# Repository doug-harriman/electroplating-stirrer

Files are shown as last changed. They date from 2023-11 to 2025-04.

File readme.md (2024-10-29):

View this project on [CADLAB.io](https://cadlab.io/project/27601).

# Firmware

## Compiler

`sudo apt install make gcc-avr avr-libc avrdude`

## Programmer

* [Amazon](https://www.amazon.com/gp/product/B09X1W2TPG/)
* [SparkFun Docs](https://www.sparkfun.com/products/11801)

### WSL USB

**Note** [Simplexity documentation](https://simplexity.atlassian.net/wiki/spaces/FWSW/pages/2658566527/Docker#Host-Access) on forwarding USB to a Docker container in WSL.

Overview of [WSL USB access](https://learn.microsoft.com/en-us/windows/wsl/connect-usb).

1. Install the WSL drivers for your kernel.
    1. Open a WSL terminal and run `usbipd list`.  This will display packages that need to be installed for your WSL kernel.
    1. Install those packages.

1. Install the [programmer Windows driver](https://github.com/adafruit/Adafruit_Windows_Drivers/releases) & plug in the programmer.
   * Windows device manager should now show `libusb-win32 devices -> USBtiny`

1. Make the USB device available to WSL
    1. Open a WSL shell.
    1. List available USB devices: `usbipd.exe list`.  Find the `USBtiny` device and note the bus ID.
        * Note: This is calling a Windows executable from WSL.
    1. Attach the USB device to WSL: `usbipd.exe wsl attach --busid <bus ID>`.  The device should now be available in WSL.
        * When you're done with the device, detach with the command above, substituting `detach` for `attach`.
    1. Verify the device is available in an WSL terminal: `lsusb`.  The device should be listed.

1. Create a `udev` rules file to make the device accessible to `avrdude`.
    1. After attaching the device to WSL per above, run `lsusb` to get the `idVendor` and `idProduct` values needed next.  The output should look something like this:
        ```
        Bus 001 Device 002: ID 1781:0c9f Multiple Vendors USBtiny
        ```
        In this example (default for the usbtiny programmer), the `idVendor` is `1781` and the `idProduct` is `0c9f`.

    1. Create a file `/etc/udev/rules.d/99-usb.rules` with the following contents:
        ```
        SUBSYSTEM=="usb", ATTR{idVendor}=="1781", ATTR{idProduct}=="0c9f", MODE="0660", GROUP="plugdev"
        ```
        * The `idVendor` and `idProduct` values are from the output of `usbipd list` above.
    1. Add your user to the group.  This will require logging out and back in.
        ```
        sudo usermod -a -G plugdev $USER
        ```
    1. Reload the `udev` rules: `sudo udevadm control --reload-rules && sudo udevadm trigger`

    NOTE: If you're unable to access, try with `sudo` permissions.

https://devblogs.microsoft.com/commandline/connecting-usb-devices-to-wsl/

https://www.krekr.nl/content/using-usbtinyisp-with-ubuntu/
https://www.tonymitchell.ca/posts/programming-avr-in-wsl-tips-and-tricks/

## Simulator

[SimAVR](https://github.com/buserror/simavr)

`sudo apt install simavr`

also installs `gdb-avr` as a dependency.

To run a simulation, you need a special build that brings in simulator symbols.
See `main-sim.c`

`make sim`

If you run the simulator with the `-g` flag, it will open up a gdb server port.
You can then attach a GDB session to that port.

## Debugger

* VSCode launch target defined in `.vscode/launch.json`
* `make sim-debug` to build the debug target and lanch the gdb-avr server process.
    * Needs to be redone every code change.
    * Make sure to kill the debugger if you relaunch.
* Select the VSCode debug and run with the AVR Debug configuration.

# Electronics

## AtTiny85

[Amazon](https://www.amazon.com/gp/product/B0CHQ97KQZ/)
* \$13.29 for 5 pieces = $2.66/piece, though had free deliverey.
* Digikey has for \$1.66/piece in quantity 1, $1.52 in quantity 25.

## Servo Motor

[Amazon](https://www.amazon.com/gp/product/B092VN3MTX/)

## Poteniometer

[Amazon](https://www.amazon.com/gp/product/B09897HR3C/)

  You may need to install the following packages for this specific kernel:
    linux-tools-5.15.90.1-microsoft-standard-WSL2
    linux-cloud-tools-5.15.90.1-microsoft-standard-WSL2

  You may also want to install one of the following packages to keep up to date:
    linux-tools-standard-WSL2
    linux-cloud-tools-standard-WSL2

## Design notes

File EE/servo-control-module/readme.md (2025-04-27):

# Workflow

> **Note**: For all operations, keep grbl software running and maintain XY home position.

> **Note**: [CADLAB.io](https://cadlab.io/project/27601/main/files) view of github repo.  Login with google account.

## PCB Prep

1. Clean the PCB with metal polisher to remove oxidation.  I use [Brasso](https://www.amazon.com/gp/product/B0000DCZ2X/).  PCB should be shiny and clean.
1. Spray paint the PCB.  Ideally would use solder mask, but the epoxy material is hard to fully ablate.  Paint ablates nicely, though it is prone to scratching.

## Design Prep
1. Panelize PCB using KiKit.  Use to provide frame and tabs with mousebites.  The `kikit.sh` script performs the process.
1. Load the panelized PCB into KiCAD.
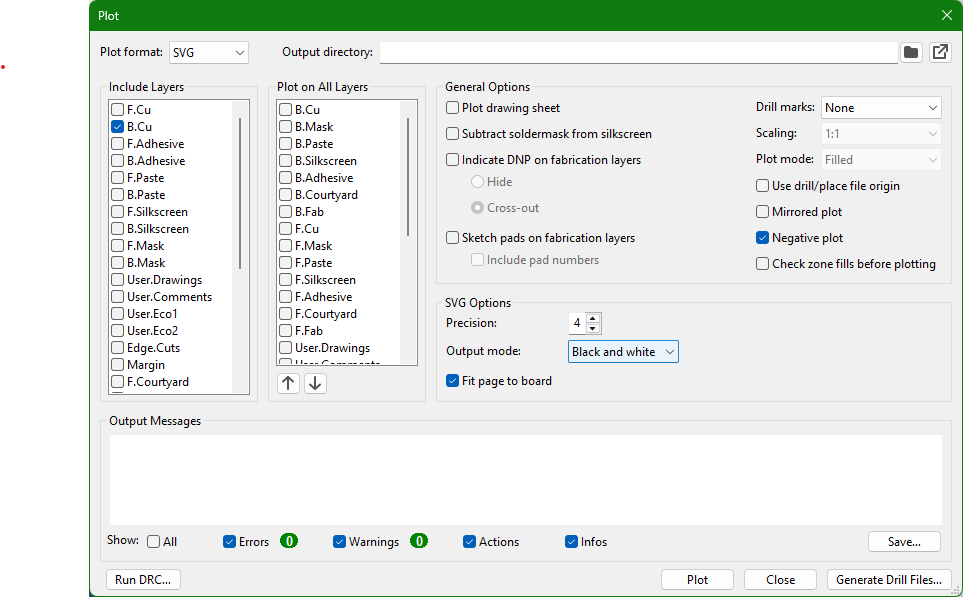
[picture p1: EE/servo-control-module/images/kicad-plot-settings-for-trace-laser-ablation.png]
PCB plot settings
1. Export a PCB image for laser ablation of the paint to expose the trace isolation areas.  Use the KiCAD "plot" function.  The image below shows the settings, assuming we're exposing the back side copper. 

## PCB Fabrication

1. Tape down PCB on mill.  Rough cut the PCB to size if that makes sense.
1. Expect to route/drill through the PCB into the supporting material, so use a sacrificial material.
1. Drill all holes, including tooling holes.
    * It is recommended
1. Route out panel from larger PCB.  Limit size of PCB we're working with to maintain chem etch solution.
1. Laser ablate spray paint in the PCB trace inverse to expose the copper for etching.
1. Chem etch the PCB to isolate the traces.
1. Laser ablate the spray paint on the solder pads.

### PCB Milling Operations

* Milling operations are generated using `pcb2gcode`.  This is a command line program that reads information from configuration files.
* `pcb2gcode` is called multiple times with different configuration files to generate the different G-code jobs (with different tools) required to machine out the PCB.

## KiCAD

KiCAD Gerber export: disable the "Use extended X2 format" option.

## PCB2GCODE

> Alternate software: https://sourceforge.net/p/pygerber2gcode/code/ci/master/tree/

* This tool worked great for generating G-code.
    * Much easier to use than FlatCAM.
    * Man page in file `pcb2gcode.pdf`.
* Example config file: `millproject`
* Generate code by running `pcb2gcode` in the same directory with `millproject`.
* Use a short list of drill sizes, or it will use exact drill size for each part.  That can lead to a lot of tooling changes.
* You can get some parameter by editing and running `pcb_calcs.py`.
    * The copper layer is very thin.  Got nice isolation with a margin of 0.5, could probably go lower.
    * This calcs the Z depth for drilling and edge cuts to cut into the tape.  It can be a bit tricky if you don't apply the height map.  Not clear if you can apply the height map to multiple files.
* Bridges shouldn't be necessary if you don't cut too fast on the edge cuts.
* Example call: https://gist.github.com/bullestock/87ed51aaadaae8b8d2f085756652eb04

## Soldermask & Silkscreen

Intended process is to apply two layers of soldermask/ink to the PCB, then use my UV laser to ablate the areas that I don't want filled in.  Overall technique from: https://www.youtube.com/watch?v=NuJlgw7E7vg.

Soldermask & silkscreen cating goes down nicely with silkscreen netting & squeegee.

* Use a squeegee to spread the ink.  I used Silicone squeegee from [Amazon](https://www.amazon.com/gp/product/B091KQFQVG/).
* Cure with UV light.  I use a resin printer cure station for 3 min with board leaning against lamp.

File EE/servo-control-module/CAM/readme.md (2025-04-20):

## Workflow

Note: For all operations, keep grbl software running and maintain XY home position.

### PCB Prep

1. Clean the PCB with metal polisher to remove oxidation.  I use [Brasso](https://www.amazon.com/gp/product/B0000DCZ2X/).  PCB should be shiny and clean.
1. Spray paint the PCB.  Ideally would use solder mask, but the epoxy material is hard to fully ablate.  Paint ablates nicely, though it is prone to scratching.

### Design Prep
1. Panelize PCB using KiKit.  Use to provide frame and tabs with mousebites.

### PCB Fabrication

1. Tape down PCB on mill.  Rough cut the PCB to size if that makes sense.
1. Expect to route/drill through the PCB into the supporting material, so use a sacrificial material.
1. Drill all holes, including tooling holes.
1. Route out panel from larger PCB.  Limit size of PCB we're working with to maintain chem etch solution.
1. Laser ablate spray paint in the PCB trace inverse to expose the copper for etching.
1. Chem etch the PCB to isolate the traces.
1. Laser ablate the spray paint on the solder pads.

# TODO

- [] Infill should not retrace.  Do bi-di laser cutting.
- [] G2 format is wrong.  Getting rejected by LaserGRBL as an invalid code.
    - Proper G2: From wherever you are, you will start. Specify the XY end point withing the G2 command.  I&J represent the center delta from the start point to the end of the arc.

Another project: https://sourceforge.net/p/pygerber2gcode/code/ci/master/tree/

## KiCAD

KiCAD Gerber export: disable the "Use extended X2 format" option.

## PCB2GCODE

* This tool worked great for generating G-code.
    * Much easier to use than FlatCAM.
    * Man page in file `pcb2gcode.pdf`.
* Example config file: `millproject`
* Generate code by running `pcb2gcode` in the same directory with `millproject`.
* Use a short list of drill sizes, or it will use exact drill size for each part.  That can lead to a lot of tooling changes.
* You can get some parameter by editing and running `pcb_calcs.py`.
    * The copper layer is very thin.  Got nice isolation with a margin of 0.5, could probably go lower.
    * This calcs the Z depth for drilling and edge cuts to cut into the tape.  It can be a bit tricky if you don't apply the height map.  Not clear if you can apply the height map to multiple files.
* Bridges shouldn't be necessary if you don't cut too fast on the edge cuts.
* Example call: https://gist.github.com/bullestock/87ed51aaadaae8b8d2f085756652eb04

## Soldermask & Silkscreen

Intended process is to apply two layers of soldermask/ink to the PCB, then use my UV laser to ablate the areas that I don't want filled in.  Overall technique from: https://www.youtube.com/watch?v=NuJlgw7E7vg.

Soldermask & silkscreen cating goes down nicely with silkscreen netting & squeegee.

* Use a squeegee to spread the ink.  I used Silicone squeegee from [Amazon](https://www.amazon.com/gp/product/B091KQFQVG/).
* Cure with UV light.  I use a resin printer cure station for 3 min with board leaning against lamp.

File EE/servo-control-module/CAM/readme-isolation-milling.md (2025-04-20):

> NOTE: This file is deprecated, captures info from when trying to do isolation routing of traces instead of chem etching.

# TODO

- [] Infill should not retrace.  Do bi-di laser cutting.
- [] G2 format is wrong.  Getting rejected by LaserGRBL as an invalid code.
    - Proper G2: From wherever you are, you will start. Specify the XY end point withing the G2 command.  I&J represent the center delta from the start point to the end of the arc.

Another project: https://sourceforge.net/p/pygerber2gcode/code/ci/master/tree/

# PCB Milling

[Good overall resource](https://hobbycnc.com/pc_board_isolation_routing/pc-board-isolation-routing-kicad/)

## KiCAD

KiCAD Gerber export: disable the "Use extended X2 format" option.

## PCB2GCODE

* This tool worked great for generating G-code.
    * Much easier to use than FlatCAM.
    * Man page in file `pcb2gcode.pdf`.
* Example config file: `millproject`
* Generate code by running `pcb2gcode` in the same directory with `millproject`.
* Use a short list of drill sizes, or it will use exact drill size for each part.  That can lead to a lot of tooling changes.
* You can get some parameter by editing and running `pcb_calcs.py`.
    * The copper layer is very thin.  Got nice isolation with a margin of 0.5, could probably go lower.
    * This calcs the Z depth for drilling and edge cuts to cut into the tape.  It can be a bit tricky if you don't apply the height map.  Not clear if you can apply the height map to multiple files.
* Bridges shouldn't be necessary if you don't cut too fast on the edge cuts.
* Example call: https://gist.github.com/bullestock/87ed51aaadaae8b8d2f085756652eb04

## Mounting PCB

It is *very* important to get the board as flat as possible.  The painters tape glued together does seem to work well if:
* Mounted to the aluminum plate, not the MDF spoilboard.
* Clean the aluminum with isopropal alcolhol ahead of time so tape adheres well.
* While glue is drying, put a large weight on the PCB.  A 5 lb sledge hammer worked well.

## Tooling

The 60 degree triangular V-cut bits worked very well.  Robust bit, and isolated nicely.
* [Inventree](http://192.168.0.120:8800/part/48/)
* [Amazon](https://www.amazon.com/gp/product/B08881PKBN?th=1)

## Autoleveling

* Use CNCjs autolevel module: https://github.com/kreso-t/cncjs-kt-ext
    * This is loaded on the Shop Server, in the CNCjs VM.
    * It's in directory `~/tmp/cncjs-kt-ext/`
    * It must be restarted every time the USB connection is made.
        * `>> node . --port /dev/ttyUSB0`
    * Create a macro or run from the command line:
        * `(#autolevel D7.5 H1.0 F20)`
        * `F` - Z-probe speed, don't go lower than 20 (mm/sec).
        * `D` - Grid spacing.  Defaults to 10 (mm).

## Soldermask & Silkscreen

Intended process is to apply two layers of soldermask/ink to the PCB, then use my UV laser to ablate the areas that I don't want filled in.  Overall technique from: https://www.youtube.com/watch?v=NuJlgw7E7vg.

Soldermask goes down nicely with:
* Cover with plastic film (overhead film works well). Need rigitity.  Plastic wrap is too soft.
* Use a squeegee to spread the ink.  I used Silicone squeegee from [Amazon](https://www.amazon.com/gp/product/B091KQFQVG/).
* Cure with UV light.  I use a resin printer cure station for 3 min with board leaning against lamp.

Essentially:
1. Lay down & cure the base soldermask (color of choice)
2. Ablate soldermask in areas where you want silkscreen.
3. Apply white ink/soldermask & cure
4. Ablate solder pads: 80% power, 200 mm/sec

### Software Tooling

While FlatCAM is a very impressive piece of Python GUI software, it's cumbersome to have to do a lot of manual stuff.  Per above, `PCB2GCODE` does a great job with the isolation routing, edge routing and drilling G-code file generation.  Once you've properly parameterized your system, it's a two second opeation to go from Gerber to G-Code.  Looking to add in the next steps in that tooling for laser ablation paths.

We need to go from Gerber to G-Code. [Gerbonara](https://gerbolyze.gitlab.io/gerbonara/#) can read Gerber files and provide graphics primitives which can be converted to G-Code by a custom Python module `gbr2grbl.py`.  This is able to draw and fill rectangles and circles, which meets the most basic of soldermask needs.

With a "dumb" implementaiton, just generating G-code geometry,
* With 0.1mm infill step size, CAMotics estimates:
    * Job time: 1m 21s
    * Total distance: 1378.1 mm.
* No infill
    * Job time: 15s
    * Total distance: 239.2 mm.

With 2D position scheduling optimization
* With 0.1mm infill step size, CAMotics estimates:
    * Job time: 1m 18s (3.7% savings)
    * Total distance: 778.0mm (43.5% savings)
* With no infill, CAMotics estimates:
    * Job time: 14.9s (0.7% savings)
    * Total distance: 222.1mm (7.1% savings)

With Traveling Salesman optimization (greedy tsp):
* With no infill, CAMotics estimates:
    * Job time: 14.93s (0.7% savings)
    * Total distance: 227.4mm (7.1% savings)

To do:

- Looks like need to flip bottom side image.
- Verify home position is correct.
- Add in laser G-code parameters as TOML config file.
- Add generation of other g-code files handled by `pcb2gcode` (drill, edge route, isolation route).
- Parameterize `pcb2gcode` to use the same TOML config file.
- Use `.gbrjob` data for `pcb2gcode` config.  Stackup has PCB and Cu thicknesses.
- Make sure I have the stackup config correct in the KiCAD PCB file.

## Overall Process

Note: For all operations, keep grbl software running and maintain XY home position.

1. Mount bare PCB to a flat but sacrificial material which is clamped to the mill bed.  PCB mounting via glued tape attached to both surfaces.  Doublesided tape will work well also.
2. If the PCB is double sided, drill corner holes that can be fitted with dowell pins for locating.
3. Autolevel board
4. Isolation route PCB back side.  Start with back side to minimize flips (assuming silksceen is front side only).
5. If double sided: clean PCB apply and cure back side soldermask, flip board, repeat steps 3 & 4 for front side.
6. Clean PCB, apply & cure soldermask.
8. Mount laser.
9. Ablate silkscreen image.
10. Apply & cure silkscreen ink
11. Ablate soldermask for solder pads
12. Remount spindle
13. Drill
14. Edge route
15. Tin exposed pads.

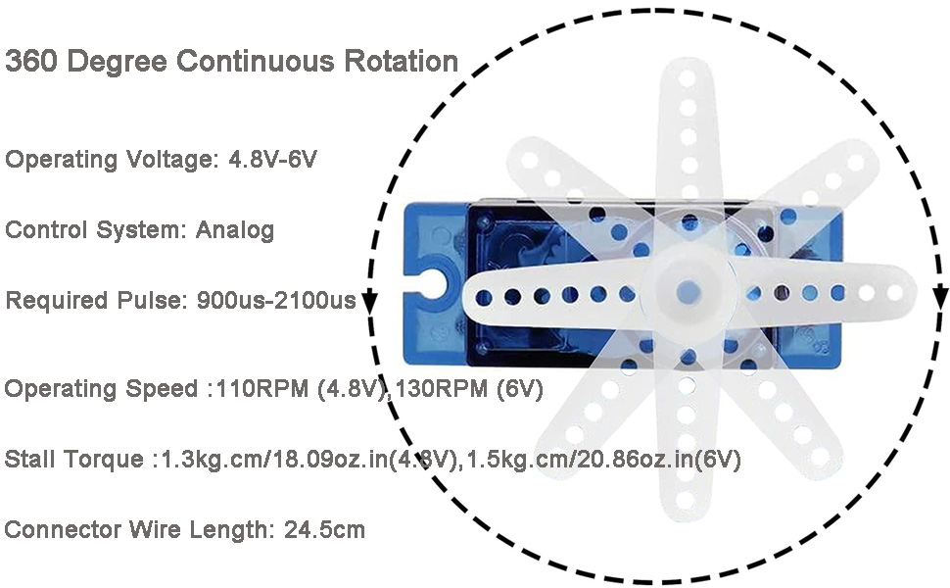
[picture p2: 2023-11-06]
Media/servo-specs.jpg

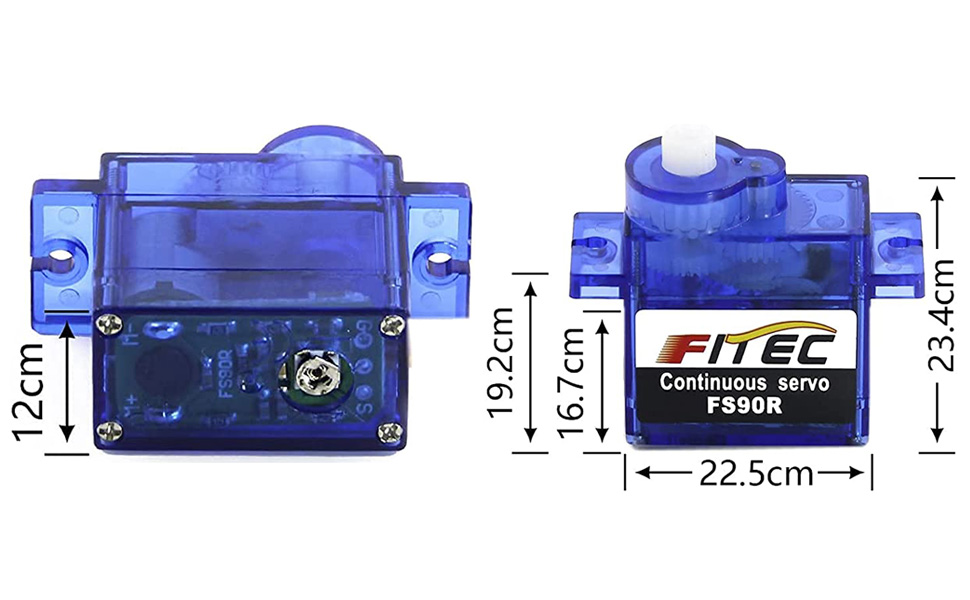
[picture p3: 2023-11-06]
Media/servo-mechanical.jpg

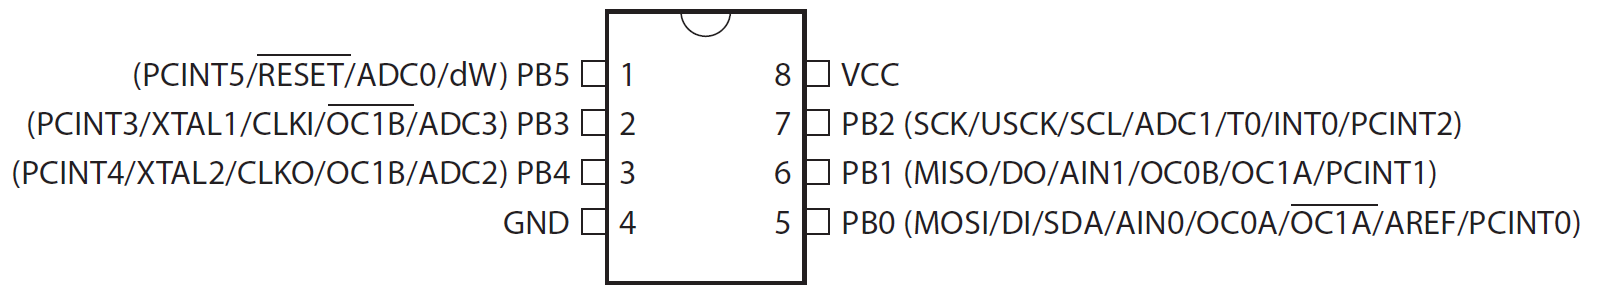
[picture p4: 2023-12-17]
EE/servo-control-module/ATtiny85-Pinout.png

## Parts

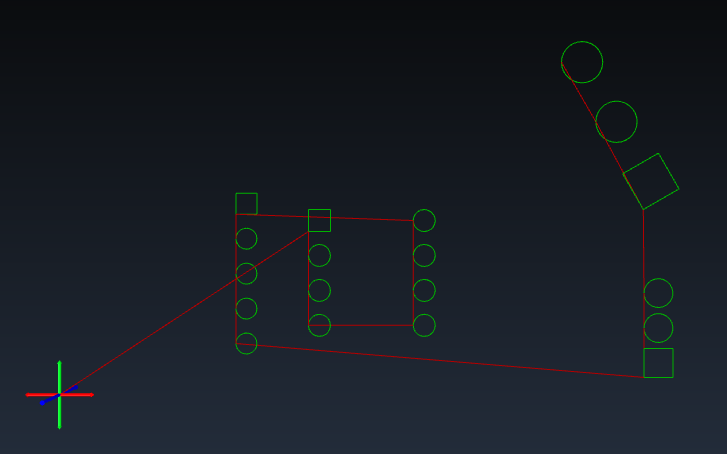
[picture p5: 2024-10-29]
EE/servo-control-module/CAM/gcode-gen-per-gerber-geometry-order.PNG

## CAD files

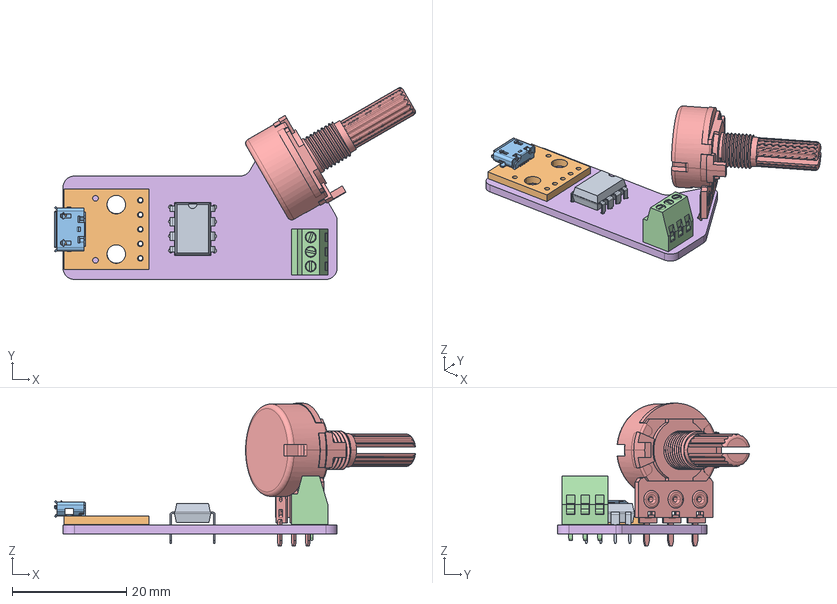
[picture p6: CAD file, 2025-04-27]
ME/PCA-with-Components.FCStd
63.2 x 33.6 x 25.0 mm
DIP-8_W7.62mm
PCA-USB-micro-breakout001
PCA-USB-micro-breakout002
kit-3pos-screw-down-terminal001
Potentiometer002
servo-control-module_PCB

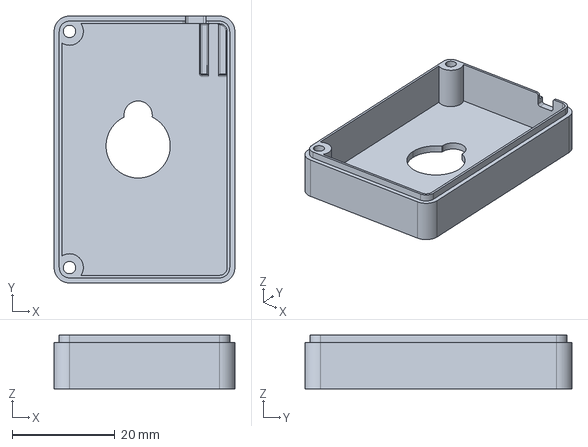
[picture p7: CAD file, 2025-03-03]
ME/Chassis-Lower.FCStd
35.2 x 52.0 x 10.5 mm

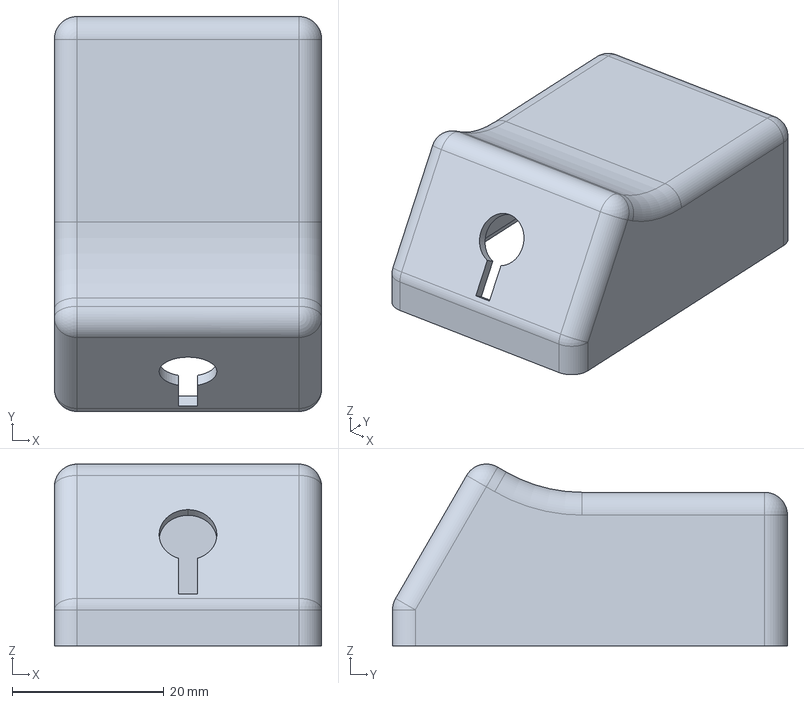
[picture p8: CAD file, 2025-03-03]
ME/Chassis-Upper.FCStd
35.2 x 52.0 x 23.9 mm

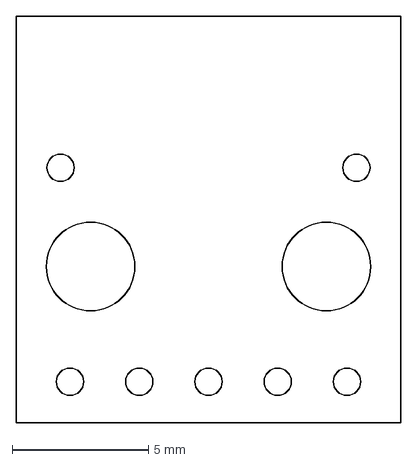
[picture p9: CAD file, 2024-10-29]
ME/PCB-USB-micro-breakout.DXF
14.1 x 14.9 mm

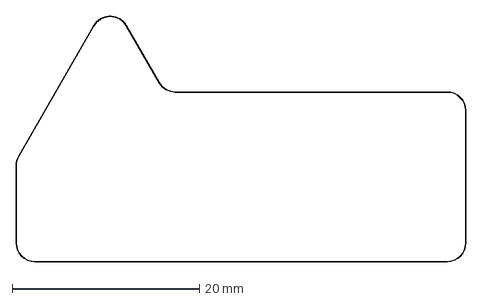
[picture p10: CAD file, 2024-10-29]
ME/pcb-speed-control.DXF
48.0 x 26.2 mm

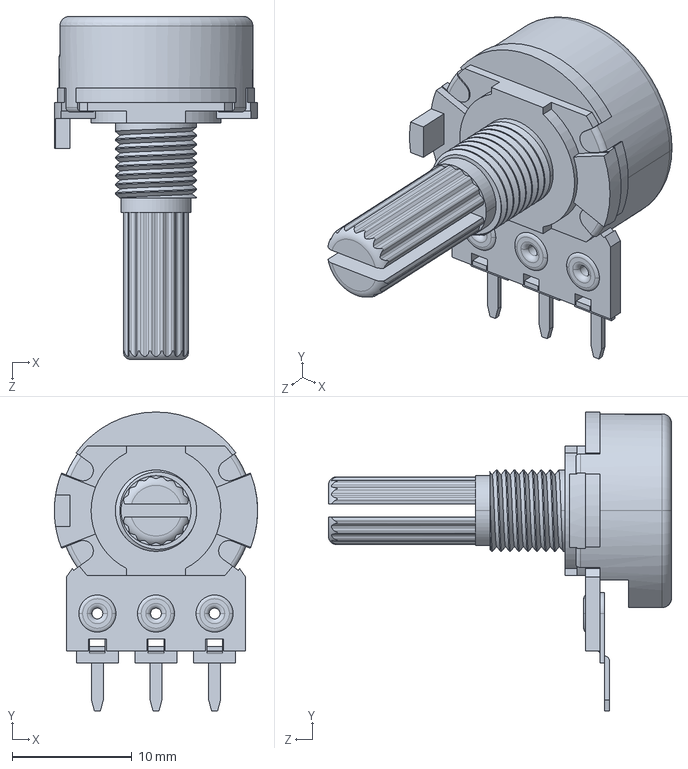
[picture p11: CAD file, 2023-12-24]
ME/Potentiometer.STEP
17.0 x 25.0 x 28.7 mm

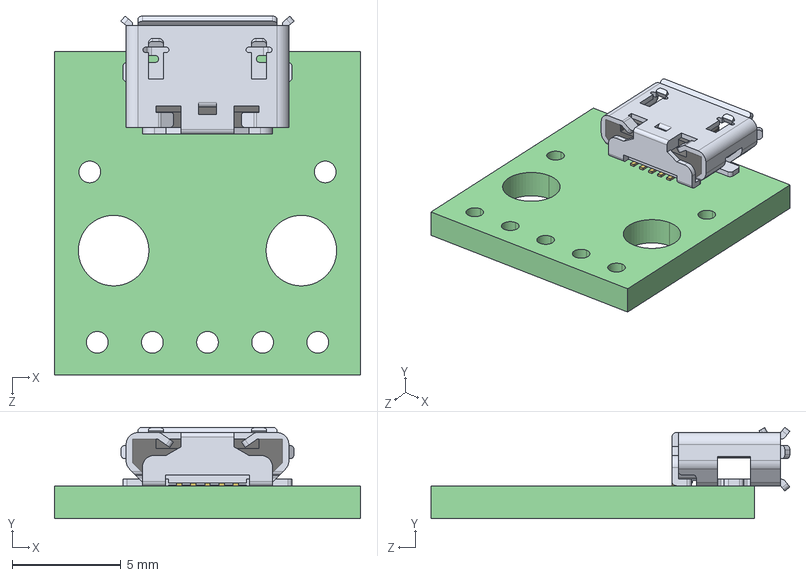
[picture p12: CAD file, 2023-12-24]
ME/PCA-USB-micro-breakout.STEP
14.1 x 4.21 x 16.5 mm
PCB-USB-micro-breakout
micro_usb_47346-0001

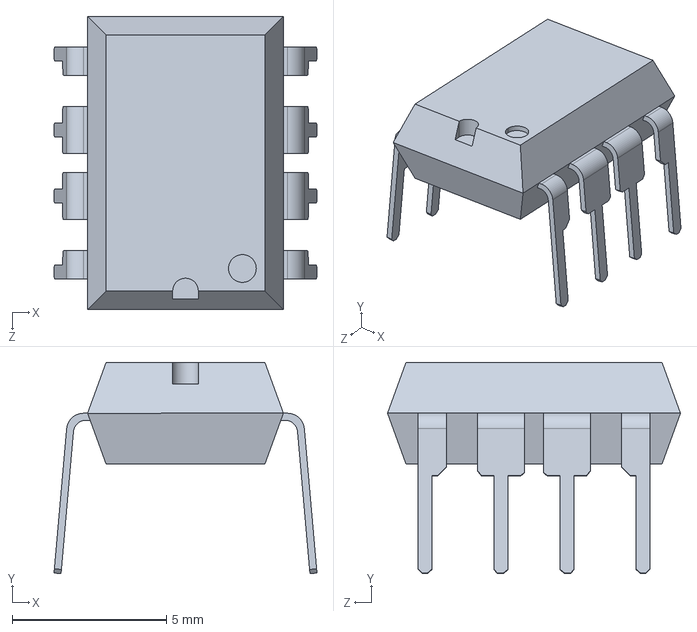
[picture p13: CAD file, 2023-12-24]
ME/DIP8N.STEP
8.53 x 6.85 x 9.50 mm

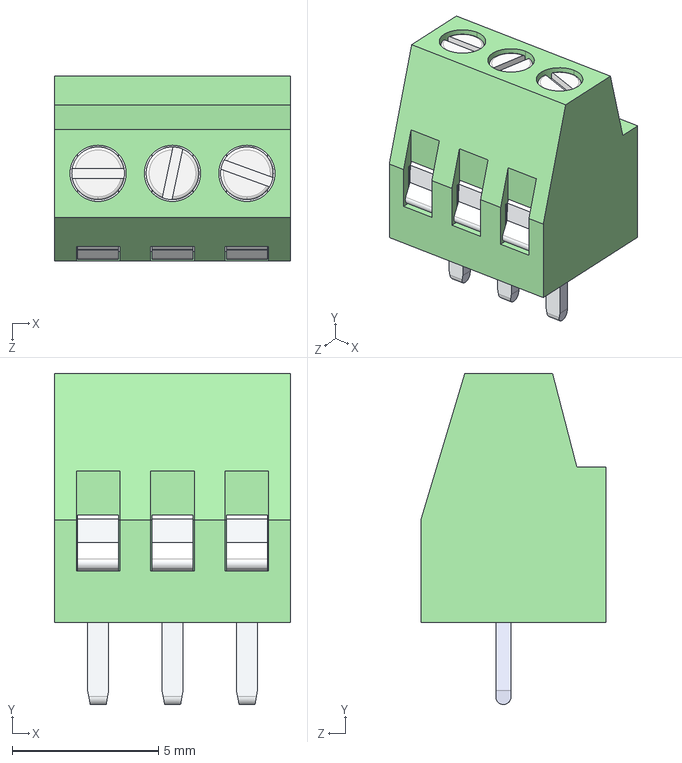
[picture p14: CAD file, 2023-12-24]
ME/kit-3pos-screw-down-terminal.STEP
8.06 x 11.3 x 6.33 mm

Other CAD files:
ME/Potentiometer-W-Color.STEP

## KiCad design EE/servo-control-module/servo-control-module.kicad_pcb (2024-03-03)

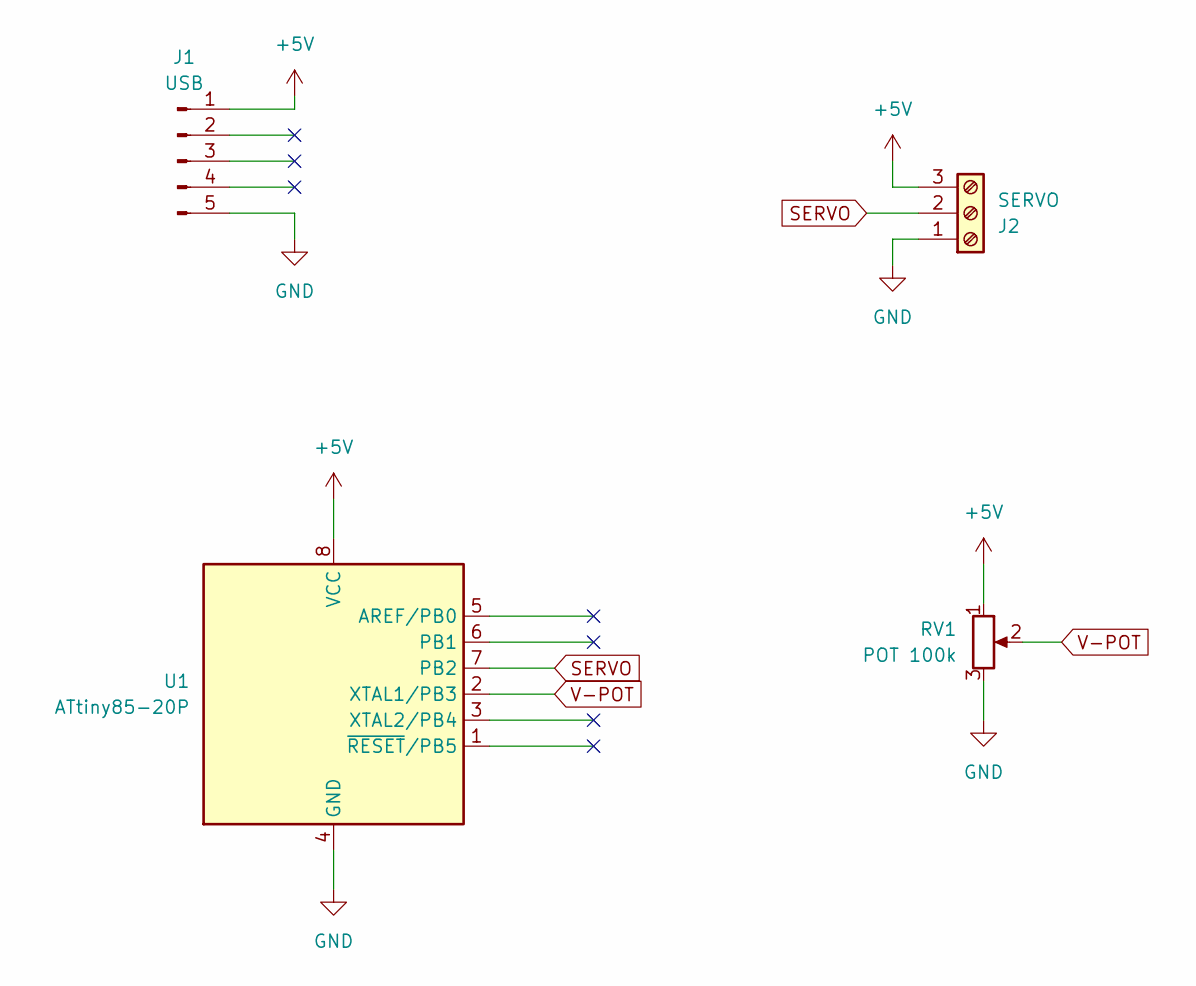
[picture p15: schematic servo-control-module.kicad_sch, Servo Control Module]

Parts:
J1: USB; USB-micro-breakout
J2: SERVO; TerminalBlock_TE_282834-3_1x03_P2.54mm_Horizontal
RV1: POT 100k; Potentiometer_Amazon_Single_Horizontal
U1: ATtiny85-20P; DIP-8_W7.62mm

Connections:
+5V: J1.1, J2.3, RV1.1, U1.8 (VCC)
GND: J1.5, J2.1, RV1.3, U1.4 (GND)
SERVO: J2.2, U1.7 (PB2)
V-POT: RV1.2, U1.2 (XTAL1/PB3)

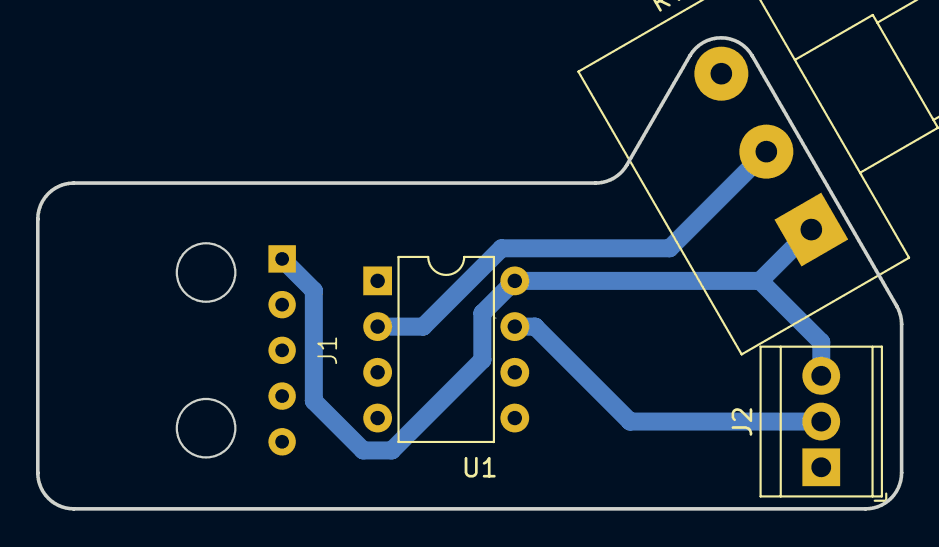
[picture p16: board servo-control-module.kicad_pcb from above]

Board: 2 copper layers, 48.0 x 26.2 mm, 4 parts (0 on the bottom side), 4 nets.

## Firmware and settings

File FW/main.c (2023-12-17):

#include "hw.h"

#include <util/delay.h>
#include <avr/sleep.h>

#ifdef SIMULATION
// Simulation configuration
#include "simavr/sim/avr/avr_mcu_section.h"
AVR_MCU(F_CPU, DEVICE);
AVR_MCU_VCD_PORT_PIN('B', PIN0, "PWM");
#endif // SIMULATION

int main(void)
{
    hw_init();

    // Servo
    // http://192.168.0.120:8800/part/1/#
    // Servo basline freq is 50 Hz.
    uint16_t period_us = 20000; // [usec]

    // Spec values
    // uint16_t period_min_us = 900;
    // uint16_t period_max_us = 2100;

    // Practical values for 5V driver per test.
    uint16_t period_mid_us = 1500; // 1.5ms is no motion

    // TODO: Spec says 100 us either side of mid
    // TODO: Get this code posted, then link servo inventree to code.
    uint16_t period_mag_us = 300; // 300 us either direction from mid.
    uint16_t period_min_us = period_mid_us - period_mag_us;
    // uint16_t period_max_us = period_mid_us + period_mag_us;

    // Initial PWM period
    uint16_t period_on_us = 1500;

    while (1)
    {
        // Start conversion
        ADCSRA |= (1 << ADSC);

        // Set PWM based on last read.
        // The PWM value is held for 5 readings: 50Hz/5 = 10Hz update
        for (uint8_t i = 0; i < 5; i++)
        {
            // On time
            PORTB |= (1 << PIN_SERVO);
            _delay_loop_2(period_on_us >> 2);

            // Off time
            PORTB &= ~(1 << PIN_SERVO);
            _delay_loop_2((period_us - period_on_us) >> 2);
        }

        // Read the ADC value
        uint8_t adc_val = ADCH;

        // Update period
        period_on_us = period_min_us + adc_val;
    }

    // Exit
    sleep_cpu();
}

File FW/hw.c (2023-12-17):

#include "hw.h"

void hw_init(void)
{
    // System clock is 1MHz, tick is 1us.
    // clk_io = system clock
    // Per datasheet, page 74, fOCnxPWM = clk_io / (prescaler * 256)
    // PWM clock period = 1 usec * 64 * 256 = 16.384 ms
    // PWM clock freq = 61 Hz.

    // Configure timer0 to fast PWM mode at 50Hz
    // TCCR0A |= (1 << WGM01) | (1 << WGM00); // Set timer0 to fast PWM mode
    // TCCR0A |= (1 << COM0A1);               // Clear OC0A on compare match, set at BOTTOM
    // TCCR0B |= (1 << CS01) | (1 << CS00);   // Set prescaler to 64
    // OCR0A = 0; // No output initially

    // MCU: ATtiny85-20P (U1)
    // Datasheet: http://ww1.microchip.com/downloads/en/DeviceDoc/atmel-2586-avr-8-bit-microcontroller-attiny25-attiny45-attiny85_datasheet.pdf

    // Net SERVO: ATtiny85-20P (U1) pin 7 -> SERVO (J1) pin 2
    // ATtiny85-20P: pin 7 = PB2
    // PB2 as output
    DDRB |= (1 << PIN_SERVO);

    // Net V-POT: ATtiny85-20P (U1) pin 2 <- POT 100k (RV1) pin 2
    // ATtiny85-20P: pin 2 = XTAL1/PB3
    // PB3 as input
    DDRB &= ~(1 << PIN_POT_100k);

    // Configure PIN_POT_100k as ADC input
    // Select ADC channel 2.
    // Zeros in REFSx uses Vcc as reference
    ADMUX |= (1 << ADLAR); // ADLAR = 1, left adjust result

    // Select PB3 (ADC3)
    ADMUX |= (1 << MUX0) | (1 << MUX1); //

    // Enable conversions
    ADCSRA |= (1 << ADEN);
}

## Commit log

2023-11-06 Initial commit due to git corruption.
    [servo-control-module.kicad_pcb, servo-control-module.kicad_sch]
2023-12-12 Updates for first milled board.
    [servo-control-module.kicad_pcb, servo-control-module.kicad_sch]
2023-12-17 Min 0.5 mm trace spacing for milling
    [servo-control-module.kicad_pcb]
2023-12-17 FW updates for ADC pin move reqd by layout.
    Using netlist.py to generate some of the code.
2023-12-21 Added footprint and 3D model for USB breakout adapter.
    [servo-control-module.kicad_pcb, servo-control-module.kicad_sch]
2023-12-24 ME design first pass.
    [8 pin IC socket.SLDPRT, DIP8N.STEP, Micro Servo 9g.SLDPRT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]
2024-01-16 Added PCB mill CAM files & info.
2024-01-16 Ignore CNC files for PCB.
2024-01-21 Update readme.md
    Added notes on soldermask & silkscreen.
2024-01-21 Python generation of G-code for silksreen from Gerber
2024-01-22 Generating G-Code from Gerber geometry description.
2024-01-26 Rectangle GCode updated for different G-code geneation paradigm. Working for Gerber rectangular pad generation.
2024-01-28 Gerber Line object supported.
2024-01-28 Silkscreen G-CODE gen working.
2024-02-18 Soldermask clearing basically working.
2024-03-03 Updated to KiCad v8
    [servo-control-module.kicad_sch]
2024-03-03 New Python module to generate fab files from KiCad files via kicad-cli.
2024-10-29 Captured new files
    [PCB-USB-micro-breakout.DXF, chassis-lower.STL, chassis-upper.STL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]
2025-03-03 Remove solidworks files
    [8 pin IC socket.SLDPRT, Micro Servo 9g.SLDPRT, PCA-USB-micro-breakout.SLDASM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]
2025-03-03 Remove STL's
    [chassis-lower.STL, chassis-upper.STL]
2025-03-03 Added chassis parts, FreeCAD
    [Chassis-Lower.FCStd, Chassis-Upper.FCStd]
2025-04-20 PCB fab documentation updates.
2025-04-27 M-CAD & E-CAD updates
    [PCA-with-Components.FCStd]
2025-04-27 KiCAD CLI runner updates for latest Python.
2025-04-27 Drill CNC file generated.
2025-04-27 PCB workflow task updates:
    * Abstracted all board filename checks.
    * added 'drills' to return PCB specified drill sizes.
    * pcb2gcode stdout dumped to /dev/null
2025-04-27 inv process now drills panel, not source pcb
2025-04-27 Drill file split by drill size.
2025-04-27 Added edge cut gerber generation.
2025-04-27 Generate trace etch mask file
